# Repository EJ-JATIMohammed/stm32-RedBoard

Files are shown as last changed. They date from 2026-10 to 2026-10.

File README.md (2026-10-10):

# STM32 RedBoard

Custom STM32F103C8T6 development board designed with KiCad, featuring USB-C, Micro-USB, CAN, Micro-SD, SWD and GPIO interfaces.

## Overview

The STM32 RedBoard is an open-source hardware development platform built around the ARM Cortex-M3-based STM32F103C8T6 microcontroller. The board integrates multiple connectivity options and interfaces, designed for embedded systems development, prototyping, and educational projects using professional-grade open-source tools.

## Features

- **Microcontroller**: ARM Cortex-M3 STM32F103C8T6 (72 MHz)
- **Memory**: 256 KB Flash, 64 KB SRAM
- **Connectivity**: USB-C and Micro-USB interfaces, CAN 2.0B support, Micro-SD card interface
- **Debugging**: Serial Wire Debug (SWD) interface for real-time debugging and firmware upload
- **Expansion**: GPIO pins for sensor integration and custom applications
- **Design**: Professional schematic and PCB layout in KiCad 10.0

## Hardware Specifications

| Specification | Value |
|---|---|
| Microcontroller | STM32F103C8T6 (ARM Cortex-M3, 72 MHz) |
| Flash Memory | 256 KB |
| SRAM | 64 KB |
| Supply Voltage | 3.3V (USB or external) |
| Interfaces | USB-C, Micro-USB, CAN, SWD, Micro-SD, GPIO |
| EDA Tool | KiCad 10.0 |

## Interfaces

### USB-C (Primary Interface)
USB Type-C 2.0 interface for primary power supply and data communication. Features reversible plug orientation and robust mechanical connection.

### Micro-USB (Secondary Interface)
USB Micro Type-B connector for alternative power and communication. Provides legacy compatibility and additional charging capability.

### CAN Bus
CAN 2.0B protocol support for vehicle diagnostics, industrial automation, and real-time control systems. Uses differential signaling with CAN_H and CAN_L lines.

### Micro-SD Card Interface
8-pin Micro SD Card Socket supporting SDIO/SPI modes. Enables data storage, firmware updates, and data logging applications.

### SWD (Serial Wire Debug)
ARM Serial Wire Debug interface for real-time debugging and firmware programming. Compatible with ST-LINK/V2, Segger J-Link, and OpenOCD-compatible debuggers.

### GPIO Expansion
Multiple GPIO pins from the STM32F103C8T6 with 3.3V logic levels (5V tolerant on selected pins). Supports digital I/O, PWM, analog input (ADC), and timer functions.

## Hardware Design

The STM32 RedBoard is fully designed in **KiCad 10.0**, a professional, open-source electronic design automation suite supporting Windows, macOS, and Linux.

### Design Files

| File | Description |
|---|---|
| `kicad_files/stm32f013 Red board.kicad_sch` | Main schematic with all component connections and interfaces |
| `kicad_files/Block_Diagram.kicad_sch` | High-level system architecture overview |
| `kicad_files/stm32f013 Red board.kicad_pcb` | PCB layout, routing, and component placement |
| `kicad_files/stm32f013 Red board.kicad_pro` | KiCad project file |

## PCB Images

Representative design documentation images:

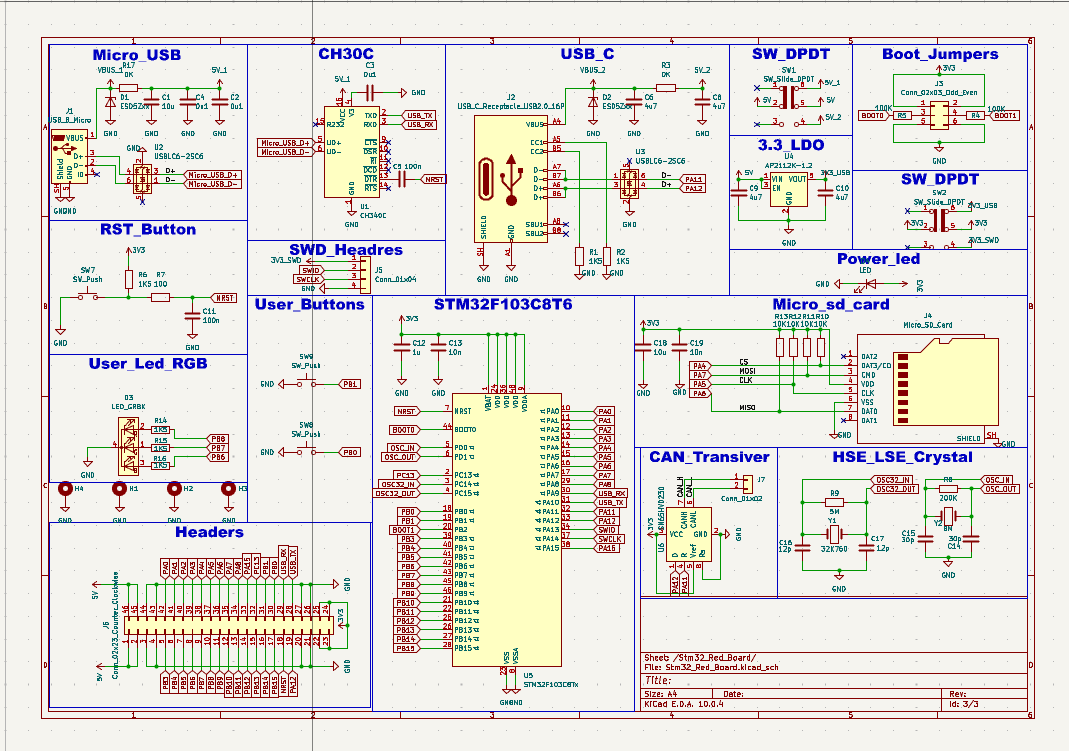
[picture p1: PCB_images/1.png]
Schematic Overview


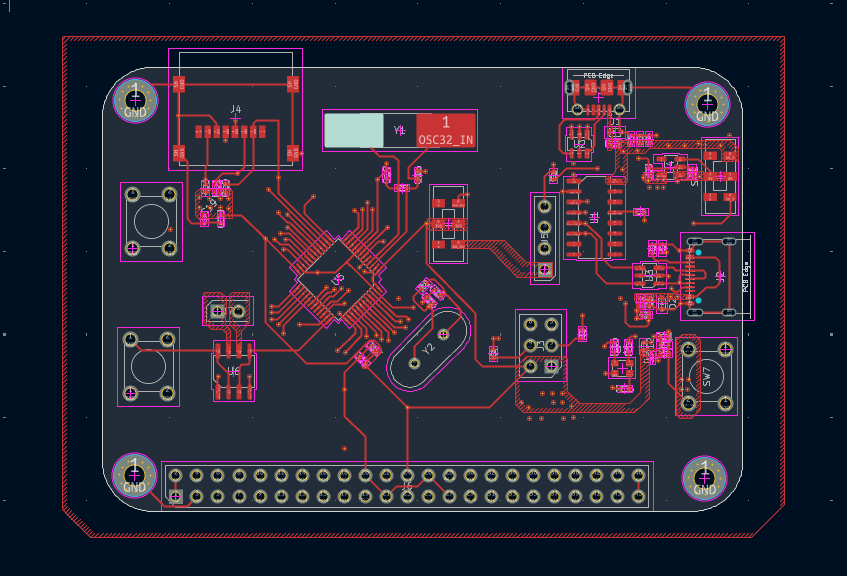
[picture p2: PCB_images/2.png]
Connector Details


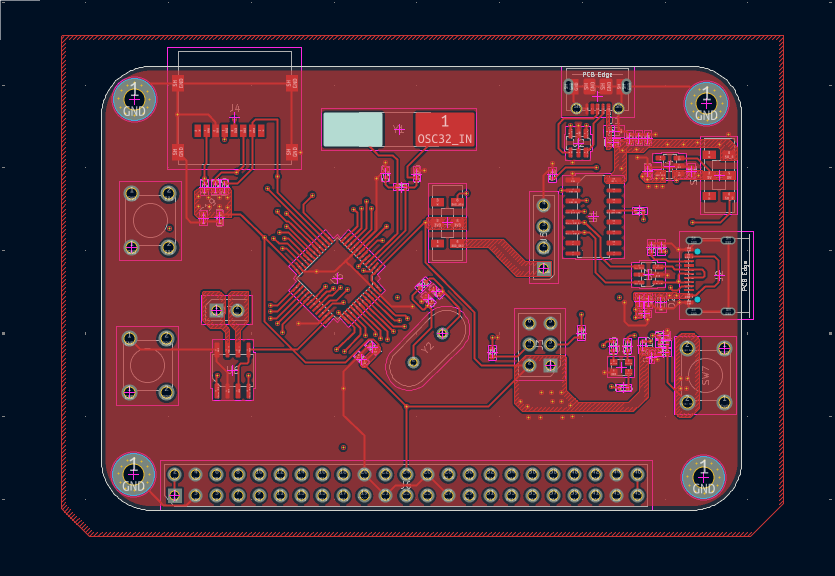
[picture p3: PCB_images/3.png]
PCB Layout


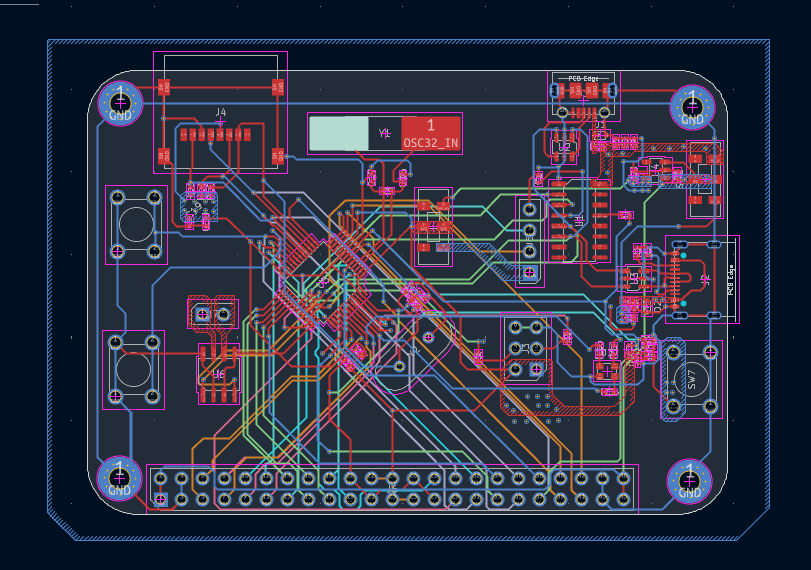
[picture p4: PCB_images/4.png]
Component Placement


## Repository Structure

```
stm32-RedBoard/
├── README.md                                        # Project documentation
├── LICENSE                                          # MIT License
├── PCB_images/                                      # Design documentation images
│   ├── 1.png
│   ├── 2.png
│   ├── 3.png
│   ├── 4.png
│   ├── 5.png
│   ├── 6.png
│   └── 7.png
├── Shematics/                                       # Schematic PDF export
│   └── stm32f013 Red board-Stm32_Red_Board.pdf
└── kicad_files/                                     # KiCad project files
    ├── Block_Diagram.kicad_sch
    ├── Stm32_Red_Board.kicad_sch
    ├── stm32f013 Red board.kicad_sch
    ├── stm32f013 Red board.kicad_pcb
    ├── stm32f013 Red board.kicad_pro
    ├── stm32f013 Red board.kicad_prl
    ├── stm32f013 Red board-Stm32_Red_Board.pdf
    └── _restore_backup_*/ (version control backups)
```

## Getting Started

### Prerequisites

- **KiCad 10.0 or later** – Download from [kicad.org](https://www.kicad.org)
- **Git** (optional, for cloning the repository)

### Opening the Project

1. **Clone the repository**
   ```bash
   git clone https://github.com/EJ-JATIMohammed/stm32-RedBoard.git
   cd stm32-RedBoard
   ```

2. **Open in KiCad**
   - Launch KiCad
   - Select **File** → **Open Project**
   - Navigate to `kicad_files/stm32f013 Red board.kicad_pro`

3. **Explore the design**
   - **Schematic**: View connections and component values
   - **PCB Layout**: Review trace routing and layer assignments
   - **Block Diagram**: See `Block_Diagram.kicad_sch` for system overview
   - **3D Viewer**: View → 3D Viewer for mechanical review

### Design Tools

- **Electrical Rules Check (ERC)**: Tools → Electrical Rules Checker
- **Design Rules Check (DRC)**: Tools → Design Rules Checker
- **Manufacturing Files**: File → Plot to generate Gerber files

## Programming and Debugging

### Supported Debuggers

- **ST-LINK/V2** – Official STMicroelectronics debugger
- **Segger J-Link** – Universal JTAG/SWD debugger
- **OpenOCD** – Open-source debugging protocol

### Development Environments

- **STM32CubeIDE** – Official STMicroelectronics IDE
- **STM32CubeMX** – Configuration and code generation
- **VSCode + ARM Toolchain** – Open-source workflow
- **PlatformIO** – Cross-platform embedded development

## Future Improvements

- **Documentation**: Detailed pinout assignments, bill of materials (BOM), assembly guide
- **Firmware Examples**: USB drivers, CAN bus applications, Micro-SD file system integration, GPIO and ADC samples
- **Hardware Validation**: Prototype fabrication and functional testing
- **Design Enhancements**: 3D STEP models, EMC/EMI review, power distribution optimization

## License

This project is released under the **MIT License**. See [LICENSE](LICENSE) for complete terms.

## Author

**EJ-JATI Mohammed**  
GitHub: [EJ-JATIMohammed](https://github.com/EJ-JATIMohammed)  
Repository: [stm32-RedBoard](https://github.com/EJ-JATIMohammed/stm32-RedBoard)

---

**Project Created**: August 2026  
**Last Updated**: October 2026  
**KiCad Version**: 10.0

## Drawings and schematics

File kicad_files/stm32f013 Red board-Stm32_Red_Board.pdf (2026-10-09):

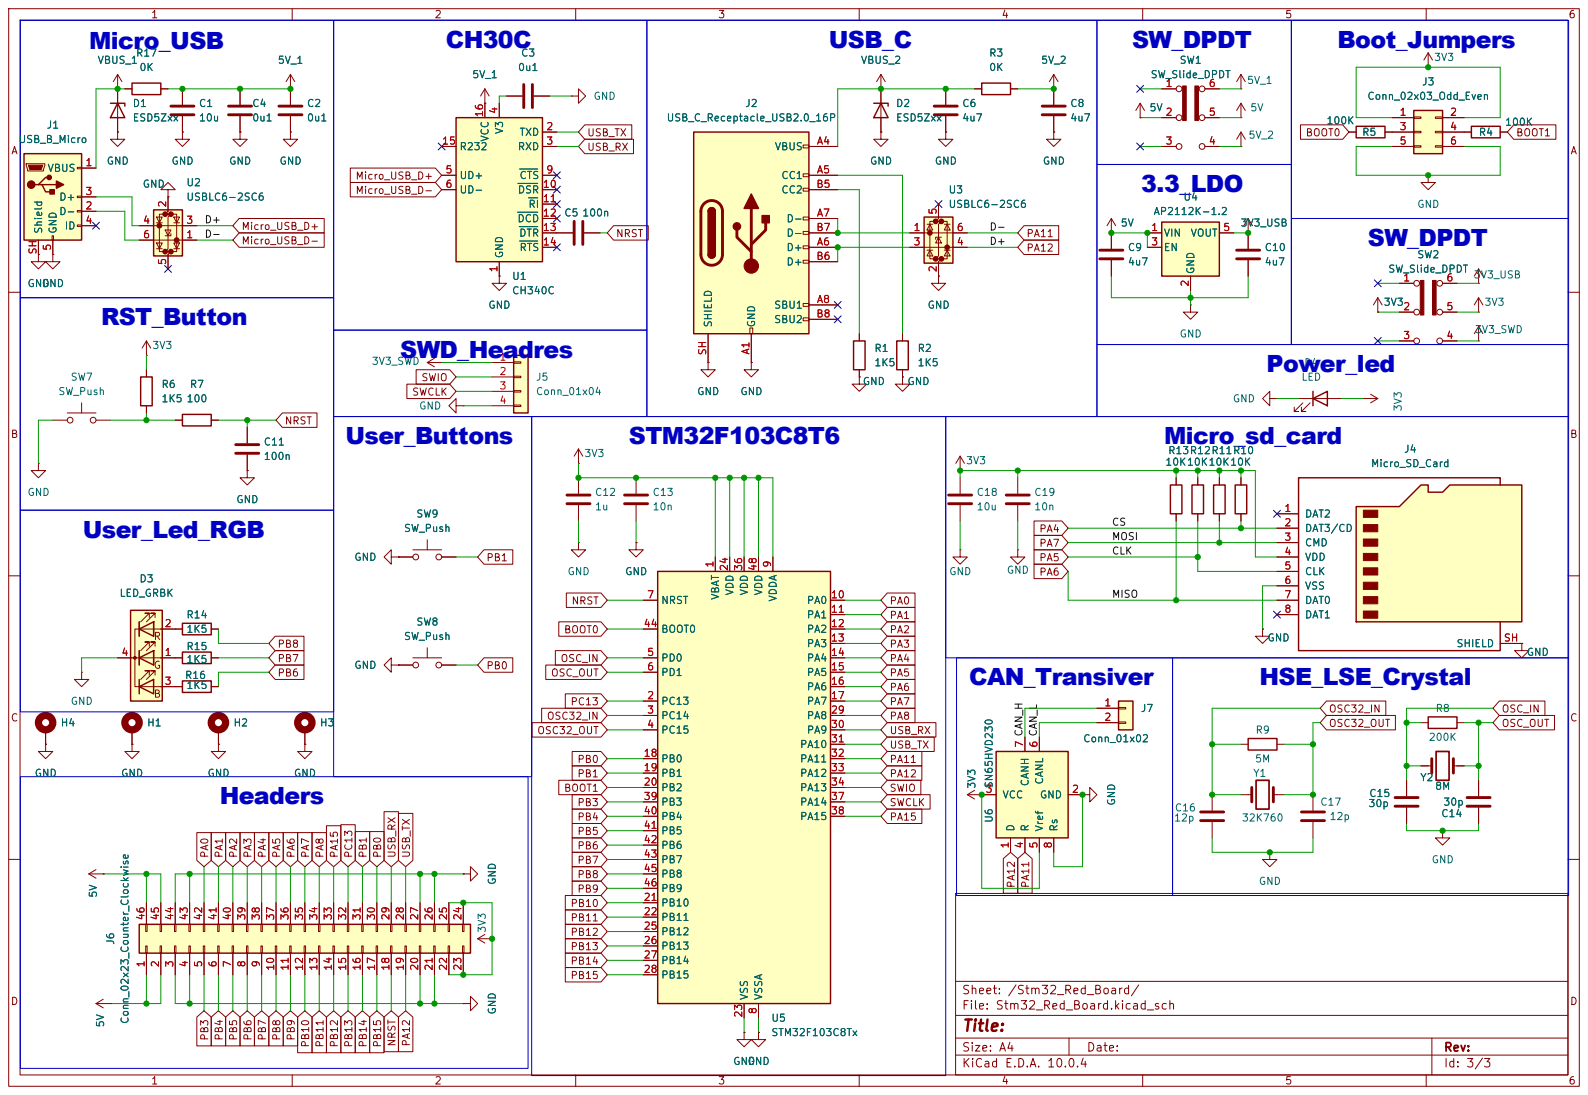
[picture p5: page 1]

4 UD+ 5 UD- 6 CTS 9 DSR 10 RI 11 DCD 12 DTR 13 RTS 14 R232 15 VCC 16 U1CH340C

4 UD+ 5 UD- 6 CTS 9 DSR 10 RI 11 DCD 12 DTR 13 RTS 14 R232 15 VCC 16 GND

Size: A4 | Rev:
KiCad E.D.A. 10.0.4 | Id: 3/3

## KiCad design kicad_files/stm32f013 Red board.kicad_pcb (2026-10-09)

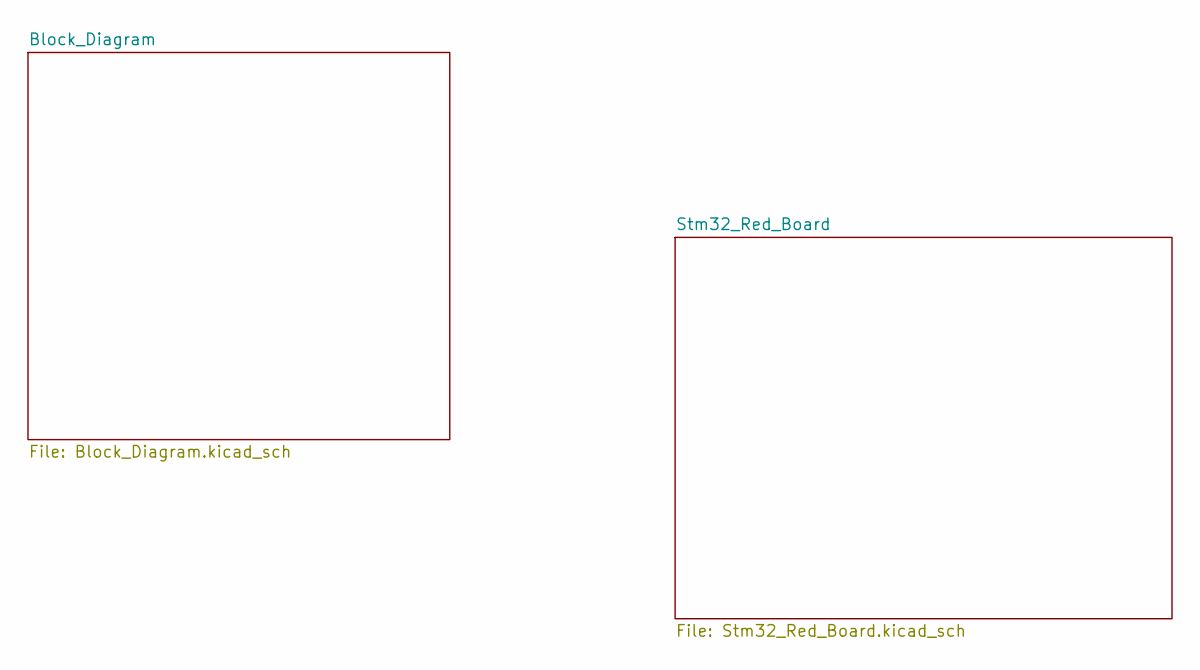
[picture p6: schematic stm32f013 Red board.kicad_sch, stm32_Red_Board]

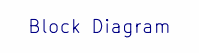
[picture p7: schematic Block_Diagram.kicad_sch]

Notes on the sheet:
Block Diagram

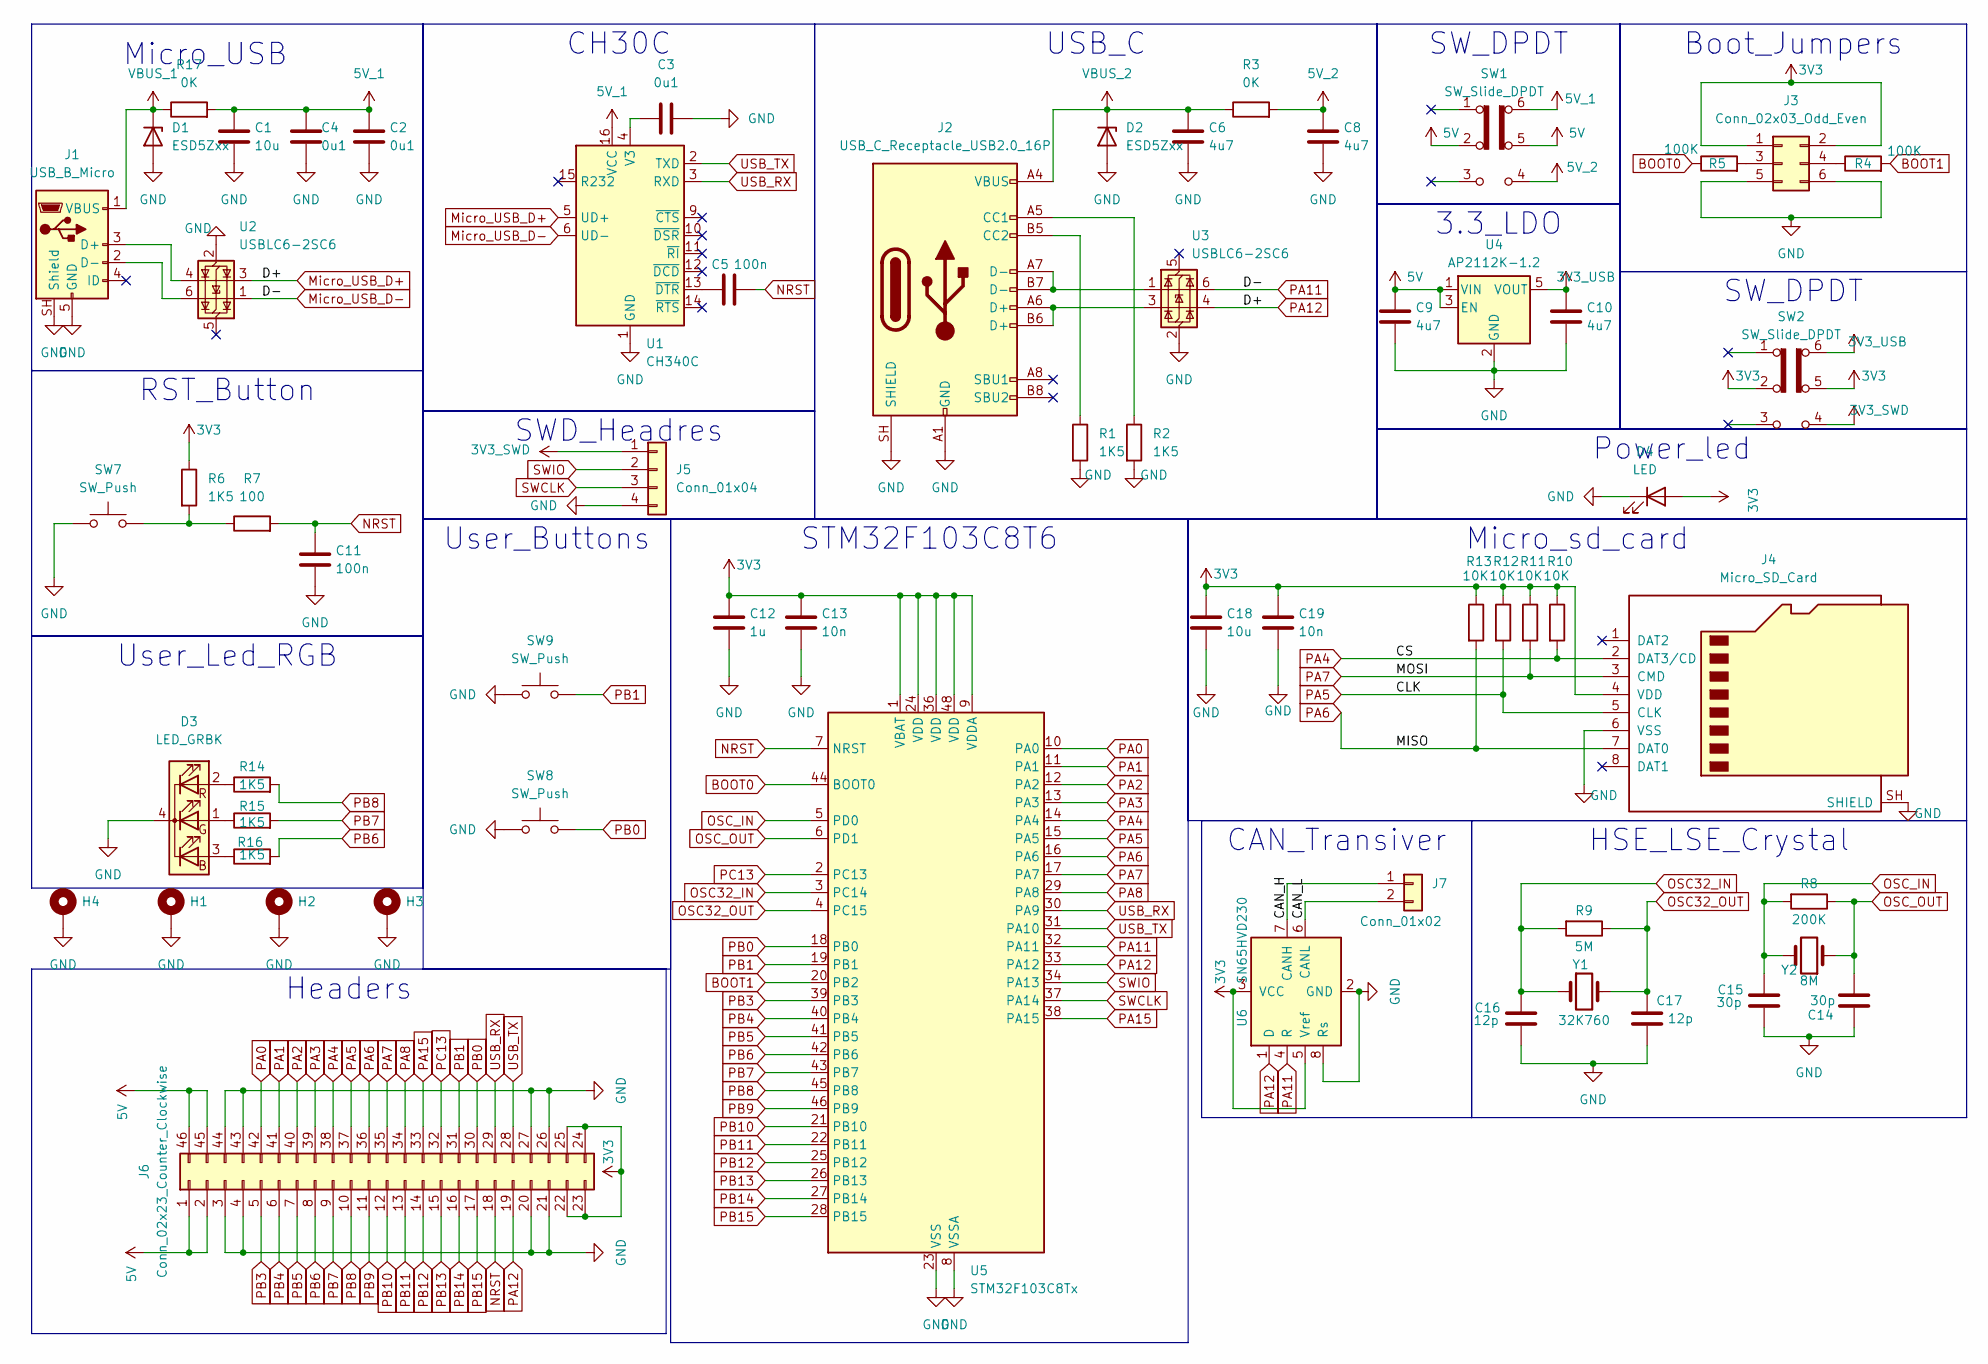
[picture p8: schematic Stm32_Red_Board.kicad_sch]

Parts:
C1, C18: 10u; C_0402_1005Metric
C2, C3, C4: 0u1; C_0402_1005Metric
C5, C11: 100n; C_0402_1005Metric
C6, C8, C9, C10: 4u7; C_0402_1005Metric
C12: 1u; C_0402_1005Metric
C13, C19: 10n; C_0402_1005Metric
C14, C15: 30p; C_0402_1005Metric
C16, C17: 12p; C_0402_1005Metric
D1, D2: ESD5Zxx; D_SOD-523
D3: LED_GRBK; LED_ASMB-KTF0-0A306
D4: LED; LED_01005_0402Metric_Pad0.57x0.30mm_HandSolder
H1, H2, H3, H4: MountingHole_Pad; MountingHole_2.5mm_Pad
J1: USB_B_Micro; USB_Micro-B_Molex-105017-0001
J2: USB_C_Receptacle_USB2.0_16P; USB_C_Receptacle_GCT_USB4105-xx-A_16P_TopMnt_Horizontal
J3: Conn_02x03_Odd_Even; PinHeader_2x03_P2.54mm_Vertical
J4: Micro_SD_Card; microSD_HC_Wuerth_693072010801
J5: Conn_01x04; PinHeader_1x04_P2.54mm_Vertical
J6: Conn_02x23_Counter_Clockwise; PinHeader_2x23_P2.54mm_Vertical
J7: Conn_01x02; PinSocket_1x02_P2.54mm_Vertical
R1, R2, R6, R14, R15, R16: 1K5; R_0402_1005Metric
R3, R17: 0K; R_0402_1005Metric
R4, R5: 100K; R_0402_1005Metric
R7: 100; R_0402_1005Metric
R8: 200K; R_0402_1005Metric
R9: 5M; R_0402_1005Metric
R10, R11, R12, R13: 10K; R_0402_1005Metric
SW1, SW2: SW_Slide_DPDT; SW_DPDT_CK_JS202011JCQN
SW7, SW8, SW9: SW_Push; SW_PUSH_6mm_H5mm
U1: CH340C; SOIC-16_3.9x9.9mm_P1.27mm
U2, U3: USBLC6-2SC6; SOT-23-6
U4: AP2112K-1.2; SOT-23-5
U5: STM32F103C8Tx; LQFP-48_7x7mm_P0.5mm
U6: SN65HVD230; SOIC-8_3.9x4.9mm_P1.27mm
Y1: 32K760; Crystal_SMD_SeikoEpson_MC405-2Pin_9.6x4.1mm_HandSoldering
Y2: 8M; Crystal_HC49-4H_Vertical

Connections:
3V3: C12.1, C13.1, C18.1, C19.1, D4.2 (A), J3.1, J3.2, J4.4 (VDD), J6.22, J6.23, J6.24, J6.25, R6.1, R10.1, R11.1, R12.1, R13.1, SW2.2 (B), SW2.5 (B), U5.1 (VBAT), U5.9 (VDDA), U5.24 (VDD), U5.36 (VDD), U5.48 (VDD), U6.3 (VCC), U6.5 (Vref)
3V3_SWD: J5.1, SW2.4 (A)
3V3_USB: C10.1, SW2.6 (C), U4.5 (VOUT)
5V: C9.1, J6.1, J6.2, J6.45, J6.46, SW1.2 (B), SW1.5 (B), U4.1 (VIN), U4.3 (EN)
5V_1: C1.1, C2.1, C4.1, R17.2, SW1.6 (C), U1.16 (VCC)
5V_2: C8.1, R3.2, SW1.4 (A)
/Stm32_Red_Board/CAN_H: J7.1, U6.7 (CANH)
/Stm32_Red_Board/CAN_L: J7.2, U6.6 (CANL)
BOOT0: R5.1, U5.44 (BOOT0)
BOOT1: R4.2, U5.20 (PB2)
GND: C1.2, C2.2, C3.2, C4.2, C6.2, C8.2, C9.2, C10.2, C11.2, C12.2, C13.2, C14.1, C15.1, C16.1, C17.1, C18.2, C19.2, D1.2 (A), D2.2 (A), D3.4 (K), D4.1 (K), H1.1 (1_1), H2.1 (1_1), H3.1 (1_1), H4.1 (1_1), J1.5 (GND), J1.SH (Shield), J2.A1 (GND), J2.A12 (GND), J2.B1 (GND), J2.B12 (GND), J2.SH (SHIELD), J3.5, J3.6, J4.6 (VSS), J4.SH (SHIELD), J5.4, J6.3, J6.4, J6.20, J6.21, J6.26, J6.27, J6.43, J6.44, R1.2, R2.2, SW7.1, SW8.1, SW9.1, U1.1 (GND), U2.2 (GND), U3.2 (GND), U4.2 (GND), U5.8 (VSSA), U5.23 (VSS), U5.35 (VSS), U5.47 (VSS), U6.2 (GND), U6.8 (Rs)
Micro_USB_D+: J6.19, U1.5 (UD+), U2.3 (I/O2), U3.4 (I/O2), U5.33 (PA12), U6.1 (D)
Micro_USB_D-: U1.6 (UD-), U2.1 (I/O1), U3.6 (I/O1), U5.32 (PA11), U6.4 (R)
NRST: C5.2, C11.1, J6.18, R7.2, U5.7 (NRST)
unnamed: D3.3 (BA), R16.1
unnamed: D3.1 (GA), R15.1
unnamed: D3.2 (RA), R14.1
unnamed: J1.3 (D+), U2.4 (I/O2)
unnamed: J1.2 (D-), U2.6 (I/O1)
unnamed: J2.A5 (CC1), R2.1
unnamed: J2.B5 (CC2), R1.1
unnamed: J2.A6 (D+), J2.B6 (D+), U3.3 (I/O2)
unnamed: J2.A7 (D-), J2.B7 (D-), U3.1 (I/O1)
unnamed: J3.3, R5.2
unnamed: J3.4, R4.1
unnamed: R6.2, R7.1, SW7.2
unnamed: C3.1, U1.4 (V3)
unnamed: C5.1, U1.13 (~DTR)
OSC32_IN: C16.2, R9.2, U5.3 (PC14), Y1.1
OSC32_OUT: C17.2, R9.1, U5.4 (PC15), Y1.2
OSC_IN: C15.2, R8.2, U5.5 (PD0), Y2.2
OSC_OUT: C14.2, R8.1, U5.6 (PD1), Y2.1
PA0: J6.42, U5.10 (PA0)
PA1: J6.41, U5.11 (PA1)
PA2: J6.40, U5.12 (PA2)
PA3: J6.39, U5.13 (PA3)
PA4: J4.2 (DAT3/CD), J6.38, R10.2, U5.14 (PA4)
PA5: J4.5 (CLK), J6.37, R12.2, U5.15 (PA5)
PA6: J4.7 (DAT0), J6.36, R13.2, U5.16 (PA6)
PA7: J4.3 (CMD), J6.35, R11.2, U5.17 (PA7)
PA8: J6.34, U5.29 (PA8)
PA15: J6.33, U5.38 (PA15)
PB0: J6.30, SW8.2, U5.18 (PB0)
PB1: J6.31, SW9.2, U5.19 (PB1)
PB3: J6.5, U5.39 (PB3)
PB4: J6.6, U5.40 (PB4)
PB5: J6.7, U5.41 (PB5)
PB6: J6.8, R16.2, U5.42 (PB6)
PB7: J6.9, R15.2, U5.43 (PB7)
PB8: J6.10, R14.2, U5.45 (PB8)
PB9: J6.11, U5.46 (PB9)
PB10: J6.12, U5.21 (PB10)
PB11: J6.13, U5.22 (PB11)
PB12: J6.14, U5.25 (PB12)
PB13: J6.15, U5.26 (PB13)
PB14: J6.16, U5.27 (PB14)
PB15: J6.17, U5.28 (PB15)
PC13: J6.32, U5.2 (PC13)
SWCLK: J5.3, U5.37 (PA14)
SWIO: J5.2, U5.34 (PA13)
USB_RX: J6.29, U1.3 (RXD), U5.30 (PA9)
USB_TX: J6.28, U1.2 (TXD), U5.31 (PA10)
VBUS_1: D1.1 (K), J1.1 (VBUS), R17.1
VBUS_2: C6.1, D2.1 (K), J2.A4 (VBUS), J2.A9 (VBUS), J2.B4 (VBUS), J2.B9 (VBUS), R3.1

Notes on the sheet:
Micro_USB
Headers
Power_led
RST_Button
CH30C
SW_DPDT
User_Buttons
STM32F103C8T6
3.3_LDO
CAN_Transiver
HSE_LSE_Crystal
User_Led_RGB
Micro_sd_card
SWD_Headres
Boot_Jumpers
USB_C

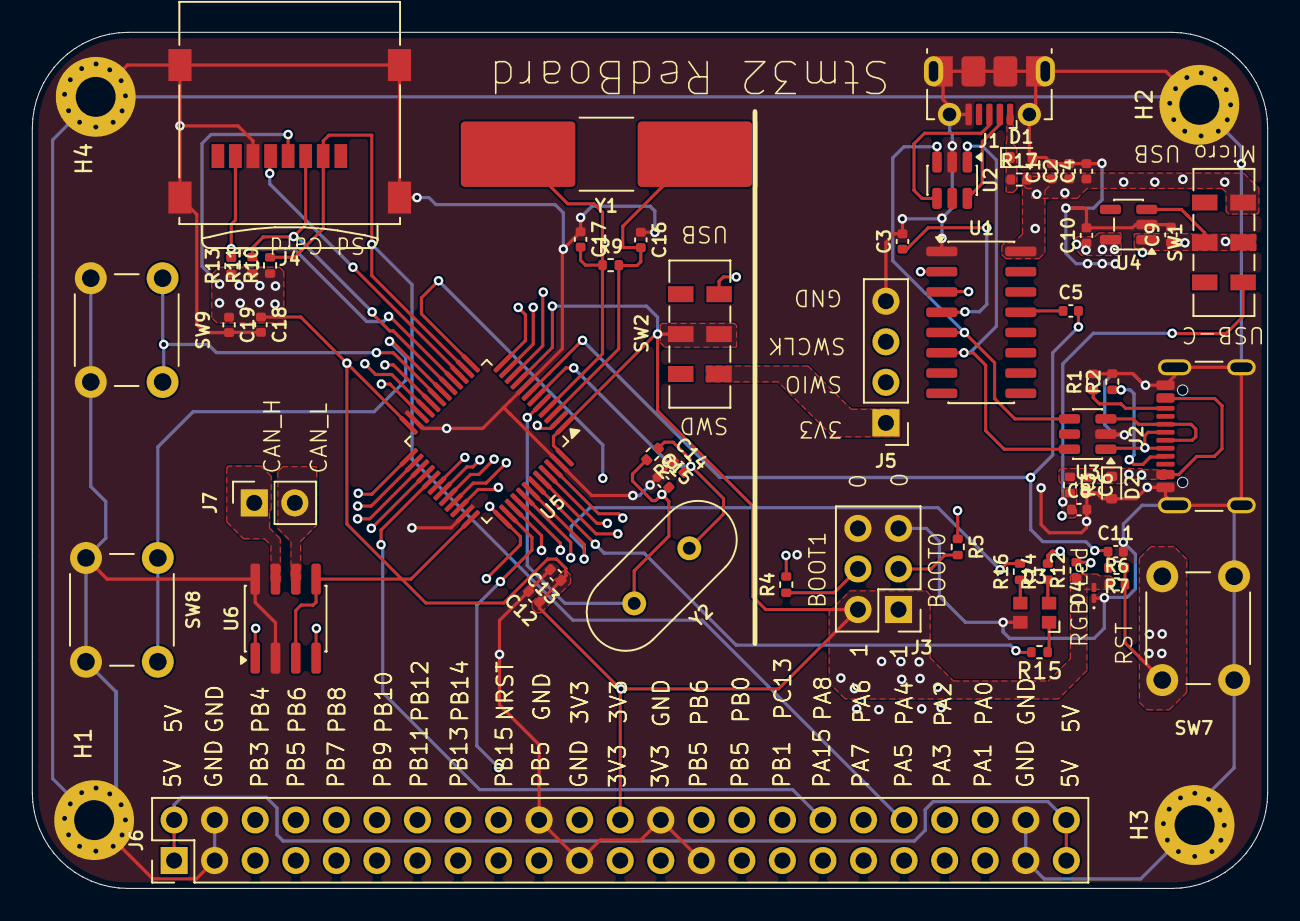
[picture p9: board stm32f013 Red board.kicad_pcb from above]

Board: 8 copper layers, 77.4 x 53.6 mm, 63 parts (0 on the bottom side), 64 nets.

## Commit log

2026-10-09 Add STM32 RedBoard PCB design
    [Block_Diagram.kicad_sch, Stm32_Red_Board.kicad_sch, stm32f013 Red board.kicad_pcb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]
2026-10-09 Add comprehensive README documentation for STM32 RedBoard project
2026-10-10 Update STM32 RedBoard
    [Block_Diagram.kicad_sch, Stm32_Red_Board.kicad_sch, stm32f013 Red board.kicad_pcb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]
2026-10-10 Improve README structure and presentation
    - Streamline project overview and remove marketing language
    - Consolidate Hardware Specifications to essentials only
    - Merge Interfaces and Connectivity into unified, concise sections
    - Remove Design Status table per requirements
    - Update Repository Contents to reflect actual structure (kicad_files, Shematics, PCB_images)
    - Clarify Getting Started with actual project file names
    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
